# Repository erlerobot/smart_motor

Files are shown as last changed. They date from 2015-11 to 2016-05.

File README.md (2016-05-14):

# smart_servo

### ATmega 328 Microcontroller development

**AVR_OpenServo_V3** -> Stable firmware. Used to create the first prototype.

**AVR_OpenServo_V3-dev** -> Firmware under development more features than the above code.

**OpenServo_Bootloader** -> The bootloader for OpenServo proyect. It is not set in the correct memory place.

### RPI development

**RPI_SmartServo** -> Code for Raspberry Pi.

**RPI_SmartServo_Client** -> Client to send commands to the SmartServo.

**RPI_SmartServo_eagle** -> Schematics and boards for eagle SmartServo.

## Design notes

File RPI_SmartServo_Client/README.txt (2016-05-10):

RPI smart motor client.

To compile gcc -o client client.c

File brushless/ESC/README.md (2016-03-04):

Interesting stuff
===========

- http://vedder.se/2014/01/a-custom-bldc-motor-controller/

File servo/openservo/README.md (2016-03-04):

# OpenServo

El CAD a utilizar en el desarrollo de este proyecto será [Eagle](http://www.cadsoftusa.com/download-eagle/).

- Features: http://www.openservo.com/DocAboutOpenServo
- Site: http://www.openservo.com/
- Wiki: http://www.openservo.com/FrontPage
- European parts list: http://headfuzz.co.uk/openservopartslist
- OpenServo step by step: http://openservo.com/StepByStep

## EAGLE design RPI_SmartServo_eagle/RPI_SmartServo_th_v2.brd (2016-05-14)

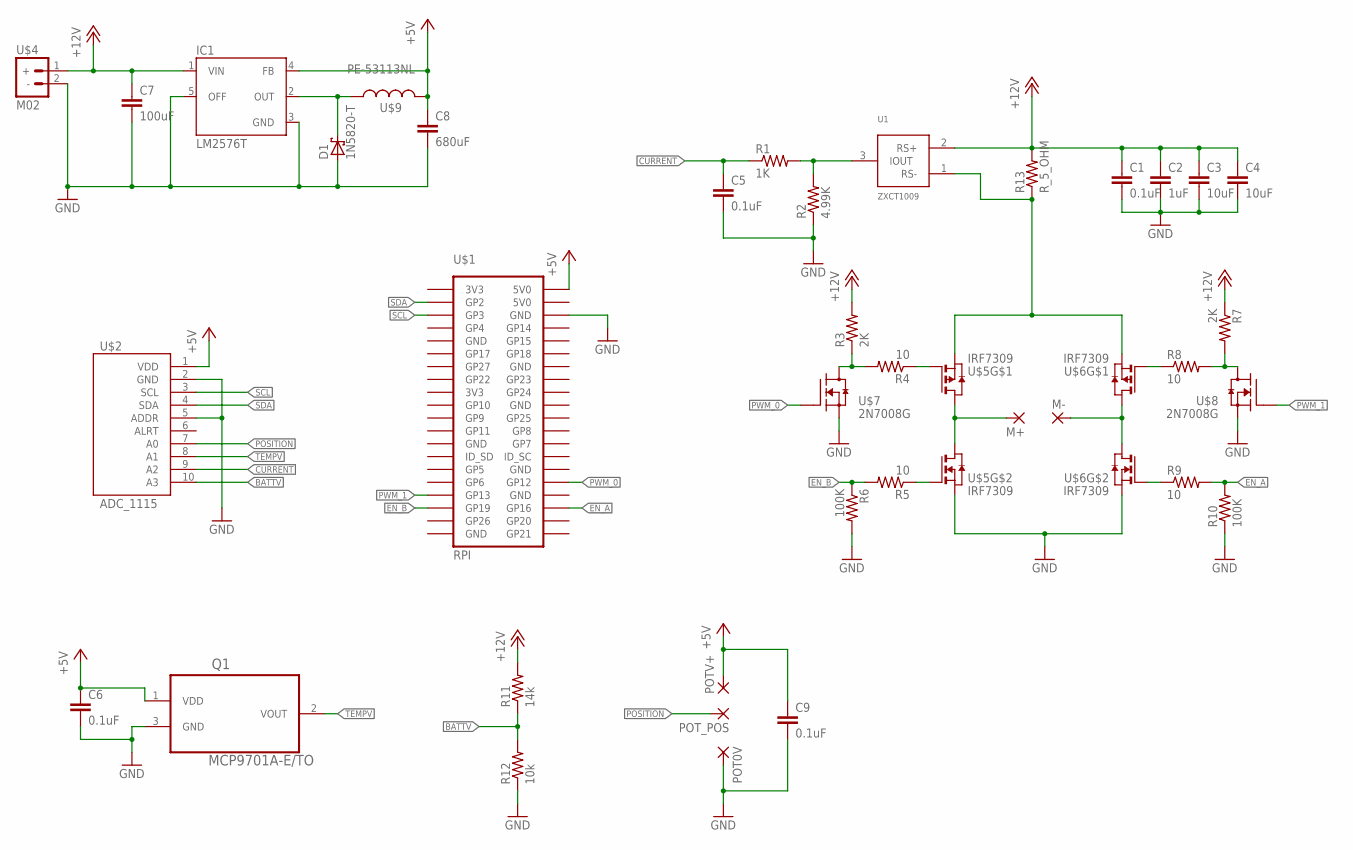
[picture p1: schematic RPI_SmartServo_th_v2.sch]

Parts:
C1, C5, C6, C9: 0.1uF; C025-025X050
C2: 1uF; C025-025X050
C3, C4: 10uF; C025-025X050
C7: 100uF; C025-025X050
C8: 680uF; C025-025X050
D1: 1N5820-T; C4111-15
IC1: LM2576T; TO220-5
M+: 1,6/0,9
M-: 1,6/0,9
POT0V: 1,6/0,9
POTV+: 1,6/0,9
POT_POS: 1,6/0,9
Q1: MCP9701A-E/TO; TO127P254X533-3
R1: 1K; AXIAL-0.4
R2: 4.99K; AXIAL-0.4
R3, R7: 2K; AXIAL-0.4
R4, R5, R8, R9: 10; AXIAL-0.4
R6, R10: 100K; AXIAL-0.4
R11: 14k; AXIAL-0.4
R12: 10k; AXIAL-0.4
R13: R_5_OHM; 0922/22
U1: ZXCT1009; SOT23
U$1: RPI; 2X20
U$2: ADC_1115; 1X10
U$4: M02; 1X02
U$5, U$6: IRF7309; SO8
U$7, U$8: 2N7008G; TO-92
U$9: PE-53113NL; KM-4

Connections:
+5V: C6.1, C8.1, C9.1, IC1.4 (FB), POTV+.1, Q1.1 (VDD), U$1.2 (5V0), U$2.1 (VDD), U$9.P$2 (2)
+12V: C1.1, C2.1, C3.1, C4.1, C7.1, IC1.1 (VIN), R3.P$2 (2), R7.P$1 (1), R11.P$2 (2), R13.2, U1.2 (RS+), U$4.1 (+)
BATTV: R11.P$1 (1), R12.P$2 (2), U$2.10 (A3)
CURRENT: C5.1, R1.P$1 (1), U$2.9 (A2)
EN_A: R9.P$2 (2), R10.P$2 (2), U$1.36 (GP16)
EN_B: R5.P$2 (2), R6.P$1 (1), U$1.35 (GP19)
GND: C1.2, C2.2, C3.2, C4.2, C5.2, C6.2, C7.2, C8.2, C9.2, D1.A, IC1.3 (GND), IC1.5 (OFF), POT0V.1, Q1.3 (GND), R2.P$1 (1), R6.P$2 (2), R10.P$1 (1), R12.P$1 (1), U$1.6 (GND), U$2.2 (GND), U$2.5 (ADDR), U$4.2 (-), U$5.1 (S), U$6.1 (S), U$7.1 (S), U$8.1 (S)
unnamed: R1.P$2 (2), R2.P$2 (2), U1.3 (IOUT)
unnamed: M+.1, U$5.5 (D), U$5.6 (D), U$5.7 (D), U$5.8 (D)
unnamed: R5.P$1 (1), U$5.2 (G)
unnamed: R4.P$1 (1), U$5.4 (G)
unnamed: M-.1, U$6.5 (D), U$6.6 (D), U$6.7 (D), U$6.8 (D)
unnamed: R9.P$1 (1), U$6.2 (G)
unnamed: R8.P$1 (1), U$6.4 (G)
unnamed: D1.C, IC1.2 (OUT), U$9.P$1 (1)
unnamed: R13.1, U1.1 (RS-), U$5.3 (S), U$6.3 (S)
unnamed: R3.P$1 (1), R4.P$2 (2), U$7.3 (D)
unnamed: R7.P$2 (2), R8.P$2 (2), U$8.3 (D)
POSITION: POT_POS.1, U$2.7 (A0)
PWM_0: U$1.32 (GP12), U$7.2 (G)
PWM_1: U$1.33 (GP13), U$8.2 (G)
SCL: U$1.5 (GP3), U$2.3 (SCL)
SDA: U$1.3 (GP2), U$2.4 (SDA)
TEMPV: Q1.2 (VOUT), U$2.8 (A1)

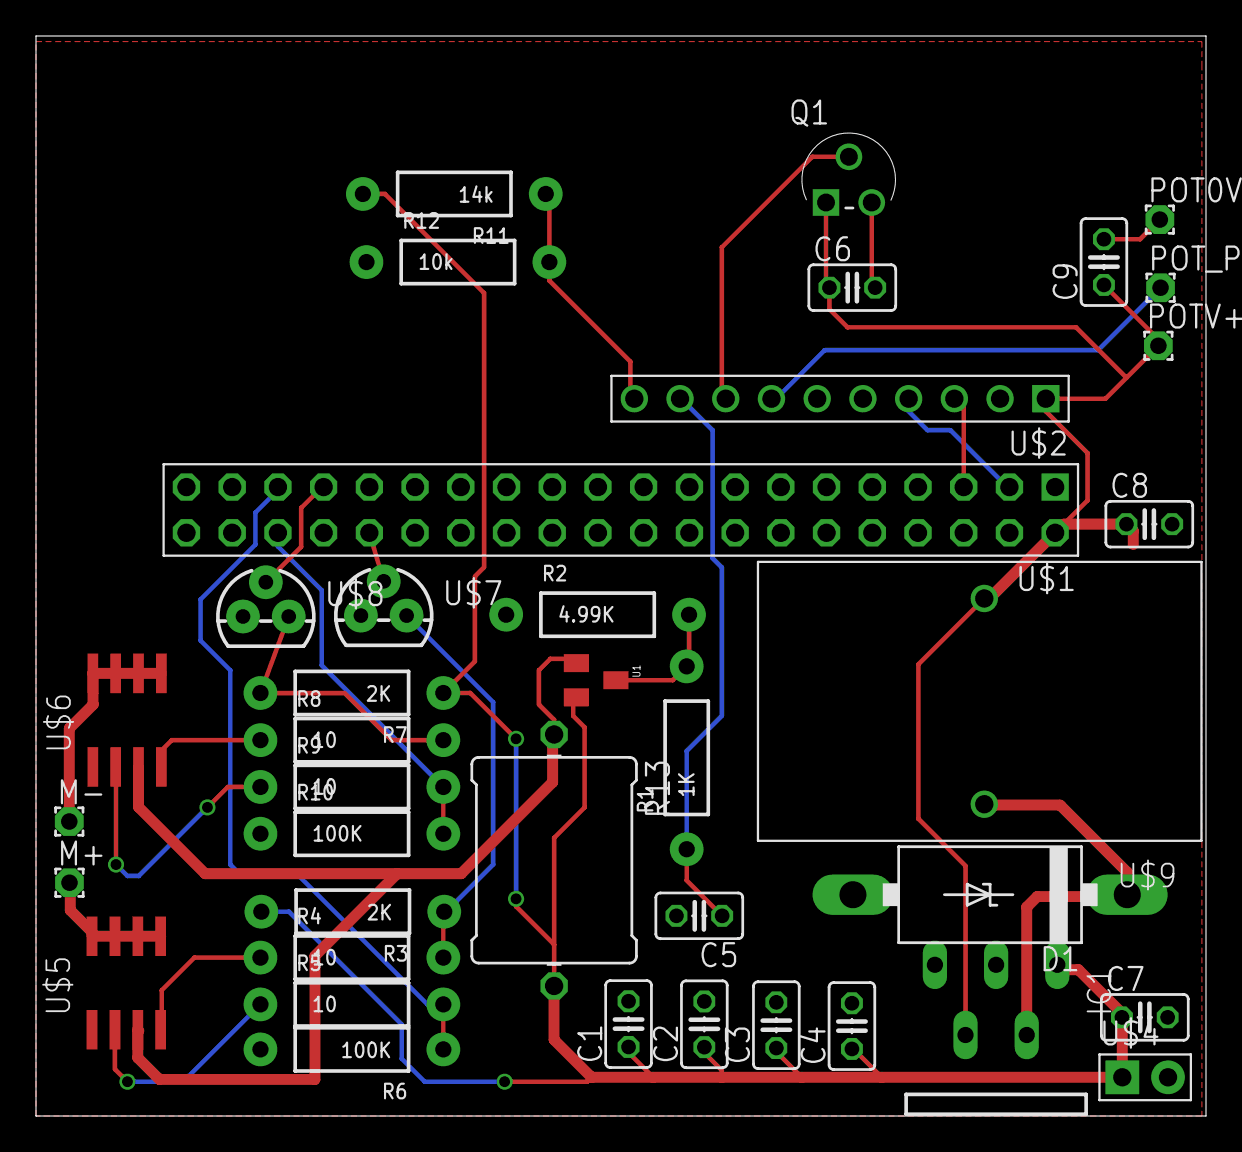
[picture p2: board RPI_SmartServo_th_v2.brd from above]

Board: 2 copper layers, 65.0 x 60.0 mm, 39 parts (0 on the bottom side), 24 nets.

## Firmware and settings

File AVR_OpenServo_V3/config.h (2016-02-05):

/*
    Copyright (c) 2006 Michael P. Thompson <mpthompson@gmail.com>

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
    $Id$
*/

#ifndef _OS_CONFIG_H_
#define _OS_CONFIG_H_ 1

// Enable (1) or disable (0) checksum verification within the
// twi.c module.  When enabled the TWI_CMD_CHECKED_TXN command
// is enabled and basic checksum validation of reads and writes
// of registers can be made for more robust communication with
// the OpenServo.  The checksum code consumes about 280 bytes
// of Flash code space when enabled.
#define TWI_CHECKED_ENABLED         0

// Enable (1) or disable (0) cubic Hermite curve following motion
// functions.  These functions allow the OpenServo to be controlled
// by keypoints along a cubic Hermite curve with each keypoint
// indicating servo position and velocity at a particular time.
#define CURVE_MOTION_ENABLED        0

// Enable (1) or disable (0) some test motion code within the
// main.c module.  This test code can be enabled to test basic
// positioning of the OpenServo without a TWI master controlling
// the OpenServo.  It should normally be disabled.
#define MAIN_MOTION_TEST_ENABLED    0

// Enable (1) or disable (0) standard servo pulse control signaling
// of the seek position.  As of 2/2/07 this feature is still under
// active development.  Please visit the OpenServo forums for the
// current status of this feature.
#define PULSE_CONTROL_ENABLED       1

// Enable (1) or disable (0) the swapping of PWM output A and B.
// This swapping must sometimes enabled depending on whether the
// positive lead to the motor is attached to MOSFET/PWM output A
// or MOSFET/PWM output B.  This option makes this easy to control
// within software.
#define SWAP_PWM_DIRECTION_ENABLED  0

// Enable (1) or disable (0) support for I2C connected encoder.
#define ENCODER_ENABLED             0

// Enable (1) or disable (0) support for full rotation
#define FULL_ROTATION_ENABLED       0

// The known OpenServo hardware types are listed below.
#define HARDWARE_TYPE_UNKNOWN           0
#define HARDWARE_TYPE_FUTABA_S3003      1
#define HARDWARE_TYPE_HITEC_HS_311      2
#define HARDWARE_TYPE_HITEC_HS_475HB    3

// By default the hardware type is unknown.  This value should be
// changed to reflect the hardware type that the code is actually
// being compiled for.
#define HARDWARE_TYPE                   HARDWARE_TYPE_UNKNOWN

// Set configuration values based on HARDWARE_TYPE.
#if (HARDWARE_TYPE == HARDWARE_TYPE_UNKNOWN)

// By default the PID gains are set to zero because they are the
// safest default when implementing an OpenServo on a new hardware.
// These defaults should be overriden by specifying the HARDWARE_TYPE
// above for actual known servo hardware.
#define DEFAULT_PID_PGAIN               0x0000
#define DEFAULT_PID_DGAIN               0x0000
#define DEFAULT_PID_IGAIN               0x0000
#define DEFAULT_PID_DEADBAND            0x00

// Specify default mininimum and maximum seek positions.  The OpenServo will
// not attempt to seek beyond these positions.
#define DEFAULT_MIN_SEEK                0x0060
#define DEFAULT_MAX_SEEK                0x03A0

// Default pwm frequency divider.
#define DEFAULT_PWM_FREQ_DIVIDER        0x0040

#elif (HARDWARE_TYPE == HARDWARE_TYPE_FUTABA_S3003)

// Futaba S3003 hardware default PID gains.
#define DEFAULT_PID_PGAIN               0x0600
#define DEFAULT_PID_DGAIN               0x0C00
#define DEFAULT_PID_IGAIN               0x0000
#define DEFAULT_PID_DEADBAND            0x01

// Futaba S3003 hardware default mininimum and maximum seek positions.
#define DEFAULT_MIN_SEEK                0x0060
#define DEFAULT_MAX_SEEK                0x03A0

// Futaba S3003 hardware default pwm frequency divider.
#define DEFAULT_PWM_FREQ_DIVIDER        0x0040

#elif (HARDWARE_TYPE == HARDWARE_TYPE_HITEC_HS_311)

// Hitec HS-311 hardware default PID gains.
#define DEFAULT_PID_PGAIN               0x0600
#define DEFAULT_PID_DGAIN               0x0C00
#define DEFAULT_PID_IGAIN               0x0000
#define DEFAULT_PID_DEADBAND            0x01

// Hitec HS-311 hardware default mininimum and maximum seek positions.
#define DEFAULT_MIN_SEEK                0x0060
#define DEFAULT_MAX_SEEK                0x03A0

// Hitec HS-311 hardware default pwm frequency divider.
#define DEFAULT_PWM_FREQ_DIVIDER        0x0040

#elif (HARDWARE_TYPE == HARDWARE_TYPE_HITEC_HS_475HB)

// Hitec HS-475HB hardware default PID gains.
#define DEFAULT_PID_PGAIN               0x0600
#define DEFAULT_PID_DGAIN               0x0C00
#define DEFAULT_PID_IGAIN               0x0000
#define DEFAULT_PID_DEADBAND            0x01

// Hitec HS-475HB hardware default mininimum and maximum seek positions.
#define DEFAULT_MIN_SEEK                0x0060
#define DEFAULT_MAX_SEEK                0x03A0

// Hitec HS-475HB hardware default pwm frequency divider.
#define DEFAULT_PWM_FREQ_DIVIDER        0x0040

#endif

#endif // _OS_ADC_H_

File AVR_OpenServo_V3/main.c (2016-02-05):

/*
    Copyright (c) 2006 Michael P. Thompson <mpthompson@gmail.com>

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
    $Id$
*/

#include <inttypes.h>
#include <avr/interrupt.h>
#include <avr/io.h>

#include "openservo.h"
#include "config.h"
#include "adc.h"
#include "eeprom.h"
#include "motion.h"
#include "pid.h"
#include "power.h"
#include "pwm.h"
#include "seek.h"
#include "pulsectl.h"
#include "timer.h"
#include "twi.h"
#include "watchdog.h"
#include "registers.h"
#include "swi2c.h"
#include "enc.h"

static void config_pin_defaults(void)
// Configure pins to their default states to conform to recommendation that all
// AVR MCU pins have a defined level.  We do this by configuring unused pins
// as inputs and enabling the internal pull-ups.
{
    // Configure unused port B pins as inputs and enable internal pull-up resistor.
    DDRB = (0<<DDB7) | (0<<DDB6) | (0<<DDB5) | (0<<DDB4) |
           (0<<DDB3) | (1<<DDB2) | (1<<DDB1) | (0<<DDB0);
    PORTB = (1<<PORTB7) | (1<<PORTB6) | (1<<PORTB5) | (1<<PORTB4) |
            (1<<PORTB3) | (0<<PORTB2) | (0<<PORTB1) | (1<<PORTB0);

    // Configure unused port C pins as inputs and enable internal pull-up resistor.
    DDRC = (0<<DDC6) | (0<<DDC5) | (0<<DDC4) |
           (0<<DDC3) | (0<<DDC2) | (0<<DDC1) | (0<<DDC0);
    PORTC = (1<<PORTC6) | (1<<PORTC5) | (1<<PORTC4) |
            (1<<PORTC3) | (1<<PORTC2) | (1<<PORTC1) | (1<<PORTC0);

    // Configure port D pins as inputs and enable internal pull-up resistor.
    DDRD = (1<<DDD7) | (0<<DDD6) | (1<<DDD5) | (1<<DDD4) |
           (1<<DDD3) | (1<<DDD2) | (0<<DDD1) | (0<<DDD0);
    PORTD = (1<<PORTD7) | (1<<PORTD6) | (0<<PORTD5) | (1<<PORTD4) |
            (0<<PORTD3) | (0<<PORTD2) | (1<<PORTD1) | (1<<PORTD0);
}


static void handle_twi_command(void)
{
    uint8_t command;

    // Get the command from the receive buffer.
    command = twi_receive_byte();

    switch (command)
    {
        case TWI_CMD_RESET:

            // Reset the servo.
            watchdog_hard_reset();

            break;

        case TWI_CMD_PWM_ENABLE:

            // Enable PWM to the servo motor.
            pwm_enable();

            break;

        case TWI_CMD_PWM_DISABLE:

            // Disable PWM to the servo motor.
            pwm_disable();

            break;

        case TWI_CMD_WRITE_ENABLE:
			
            // Enable write to read/write protected registers.
            registers_write_enable();

            break;

        case TWI_CMD_WRITE_DISABLE:

            // Disable write to read/write protected registers.
            registers_write_disable();

            break;

        case TWI_CMD_REGISTERS_SAVE:

            // Save register values into EEPROM.
            eeprom_save_registers();

            break;

        case TWI_CMD_REGISTERS_RESTORE:

            // Restore register values into EEPROM.
            eeprom_restore_registers();

            break;

        case TWI_CMD_REGISTERS_DEFAULT:

            // Restore register values to factory defaults.
            registers_defaults();
            break;

        case TWI_CMD_EEPROM_ERASE:

            // Erase the EEPROM.
            eeprom_erase();

            break;

        case TWI_CMD_VOLTAGE_READ:

            // Request a voltage reading.
            adc_read_voltage();

            break;

#if CURVE_MOTION_ENABLED
        case TWI_CMD_CURVE_MOTION_ENABLE:

            // Enable curve motion handling.
            motion_enable();

            break;

        case TWI_CMD_CURVE_MOTION_DISABLE:

            // Disable curve motion handling.
            motion_disable();

            break;

        case TWI_CMD_CURVE_MOTION_RESET:

            // Reset the motion to the current position.
#if ENCODER_ENABLED
            motion_reset(enc_get_position_value());
#else
            motion_reset(adc_get_position_value());
#endif

            break;

        case TWI_CMD_CURVE_MOTION_APPEND:

            // Append motion curve data stored in the registers.
            motion_append();

            break;
#endif

        default:

            // Ignore unknown command.
            break;
    }
}


int main (void)
{	
    // Configure pins to the default states.
    config_pin_defaults();
	
    // Initialize the watchdog module.
    watchdog_init();

    // First, initialize registers that control servo operation.
    registers_init();

    // Initialize the PWM module.
    pwm_init();

    // Initialize the ADC module.
    adc_init();

    // Initialize the PID algorithm module.
    pid_init();
	
#if CURVE_MOTION_ENABLED
    // Initialize curve motion module.
    motion_init();
#endif

    // Initialize the power module.
    power_init();

#if PULSE_CONTROL_ENABLED
    pulse_control_init();
#endif

#if ENCODER_ENABLED
    // Initialize software I2C to talk with encoder.
    swi2c_init();
#endif
	
    // Initialize the TWI slave module.
    twi_slave_init(registers_read_byte(REG_TWI_ADDRESS));
	
    // Finally initialize the timer.
    timer_set(0);

    // Enable interrupts.
    sei();
	
#if !ENCODER_ENABLED
    // Wait until initial position value is ready.
//    while (!adc_position_value_is_ready());				////atasco papel
#endif
	
#if CURVE_MOTION_ENABLED
    // Reset the curve motion with the current position of the servo.
#if ENCODER_ENABLED
    motion_reset(enc_get_position_value());
#else
    motion_reset(adc_get_position_value());
#endif
#endif

    // Set the initial seek position and velocity.
#if ENCODER_ENABLED
    registers_write_word(REG_SEEK_POSITION_HI, REG_SEEK_POSITION_LO, enc_get_position_value());
#else
    registers_write_word(REG_SEEK_POSITION_HI, REG_SEEK_POSITION_LO, adc_get_position_value());
#endif
    registers_write_word(REG_SEEK_VELOCITY_HI, REG_SEEK_VELOCITY_LO, 0);

    // XXX Enable PWM and writing.  I do this for now to make development and
    // XXX tuning a bit easier.  Constantly manually setting these values to
    // XXX turn the servo on and write the gain values get's to be a pain.
    pwm_enable();
    registers_write_enable();
	
    // This is the main processing loop for the servo.  It basically looks
    // for new position, power or TWI commands to be processed.
    for (;;)
    {	
        // Is position value ready?
#if !ENCODER_ENABLED
        if (adc_position_value_is_ready())
		
#endif
        {   //PORTD = (1<<PORTD5);
            int16_t pwm;
            int16_t position;

#if PULSE_CONTROL_ENABLED
            // Give pulse control a chance to update the seek position.
            pulse_control_update();
#endif

#if CURVE_MOTION_ENABLED
            // Give the motion curve a chance to update the seek position and velocity.
            motion_next(10);
#endif

            // Get the new position value.
#if ENCODER_ENABLED
            position = (int16_t) enc_get_position_value();
#else
            position = (int16_t) adc_get_position_value();
#endif

#if ENCODER_ENABLED
            if (position >= 0)
#endif
            {
                // Call the PID algorithm module to get a new PWM value.
                pwm = pid_position_to_pwm(position);

                // Update the servo movement as indicated by the PWM value.
                // Sanity checks are performed against the position value.
                pwm_update(position, pwm);
            }
        }

        // Is a power value ready?
        if (adc_power_value_is_ready())
        {
            // Get the new power value.
            uint16_t power = adc_get_power_value();

            // Update the power value for reporting.
            power_update(power);
        }

        // Was a command recieved?
        if (twi_data_in_receive_buffer())
        {
            // Handle any TWI command.
            handle_twi_command();
        }

#if MAIN_MOTION_TEST_ENABLED
        // This code is in place for having the servo drive itself between
        // two positions to aid in the servo tuning process.  This code
        // should normally be disabled in config.h.
#if CURVE_MOTION_ENABLED
        if (motion_time_left() == 0)
        {
            registers_write_word(REG_CURVE_DELTA_HI, REG_CURVE_DELTA_LO, 2000);
            registers_write_word(REG_CURVE_POSITION_HI, REG_CURVE_POSITION_LO, 0x0100);
            motion_append();
            registers_write_word(REG_CURVE_DELTA_HI, REG_CURVE_DELTA_LO, 1000);
            registers_write_word(REG_CURVE_POSITION_HI, REG_CURVE_POSITION_LO, 0x0300);
            motion_append();
            registers_write_word(REG_CURVE_DELTA_HI, REG_CURVE_DELTA_LO, 2000);
            registers_write_word(REG_CURVE_POSITION_HI, REG_CURVE_POSITION_LO, 0x0300);
            motion_append();
            registers_write_word(REG_CURVE_DELTA_HI, REG_CURVE_DELTA_LO, 1000);
            registers_write_word(REG_CURVE_POSITION_HI, REG_CURVE_POSITION_LO, 0x0100);
            motion_append();
        }
#else
        {
            // Get the timer.
            uint16_t timer = timer_get();

            // Reset the timer if greater than 800.
            if (timer > 800) timer_set(0);

            // Look for specific events.
            if (timer == 0)
            {
                registers_write_word(REG_SEEK_HI, REG_SEEK_LO, 0x0100);
            }
            else if (timer == 400)
            {
                registers_write_word(REG_SEEK_HI, REG_SEEK_LO, 0x0300);
            }
        }
#endif
#endif
    }
	
	
	
    return 0;
}

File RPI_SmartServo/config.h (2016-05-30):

/**
 *  project  :  RPI_SmartServo          
 *  
 *  @file config.h
 *  @brief Configuration file for RPI_SmartServo
 * 
 *  @note 
 *
 *      none
 *
 *  \code
 *  MODIFICATION HISTORY:
 *
 *  Ver   Who        Date        Changes
 *  ----- ---------- ----------  -------------------------------------
 *  1.00 jlamperez  6/3/2016  First release
 * 
 *  \endcode
 *
 *  Copyright (c) 2016, Jorge Lampérez. All rights reserved.
 */

#ifndef CONFIG_H_
#define CONFIG_H_ 1

#define RPI_0 0
#define RPI_1 1
#define RPI_2 2

#define BITS_12 12
#define BITS_10 10

/** Define different options for RPI Servo.
 @todo todo
 Configuration for the ADS1115
 */
#define RPI_BOARD RPI_2
#define ADC_RESOLUTION BITS_12

/**
 *  TIMER configuration.
 */
//#define CONFIG_TIMER 100000000 //100ms
//#define CONFIG_TIMER  10000000 //10ms
#define CONFIG_TIMER  50000000 //50ms Good
//#define CONFIG_TIMER  30000000 //30ms Falla
//#define CONFIG_TIMER  40000000 //40ms Falla
//#define CONFIG_TIMER  45000000 //45ms Falla
/**
 *  Debugger configuration.
 */

//#define CONFIG_DEBUGGER 0

/**
 *  Board.  RPI_0, RPI_1, RPI_2
 *  PWM and EN GPIO can be changed
 */

/*
 * RPIO_0
 */
#if (RPI_BOARD == 0)
// PWM GPIO
#define CONFIG_PWM0_GPIO X // pin X
#define CONFIG_PWM1_GPIO X // pin X
// EN_A and EN_N GPIO
#define CONFIG_EN_A_GPIO X //pin X
#define CONFIG_EN_B_GPIO X //pin X
/*
 * RPIO_1
 */
#elif (RPI_BOARD == 1)
// PWM GPIO
#define CONFIG_PWM0_GPIO 12 // pin X
#define CONFIG_PWM1_GPIO 13 // pin X
// EN_A and EN_N GPIO
#define CONFIG_EN_A_GPIO 16 //pin X
#define CONFIG_EN_B_GPIO 19 //pin X
/*
 * RPIO_2
 */
#elif (RPI_BOARD == 2)
// PWM GPIO
#define CONFIG_PWM0_GPIO 12 // pin 32
#define CONFIG_PWM1_GPIO 13 // pin 33
// EN_A and EN_N GPIO
#define CONFIG_EN_A_GPIO 16 //pin36
#define CONFIG_EN_B_GPIO 19 //pin35
#endif


/**
 *  ADC resolution configuration for pid and pwm
 */

/*
 * ADC 10 bits
 */
#if (ADC_RESOLUTION == BITS_10)
/**
 *  ADC and Potentiometer resolution values to convert to voltage and grades
 */
#define ADC_RES_CONSTANT 0.006  //(6.1444/2^10)
#define POT_RES_CONSTANT 3.78   //(5V/ADC_RES)/220º
/**
 *  PID configuration.
 */

// The minimum and maximum servo position as defined by 10-bit ADC values.
#define CONFIG_PID_MIN_POSITION (0)
//The ADC effective bits are 15 but because of noise we take 10.
#define CONFIG_PID_MAX_POSITION (1024)
// The minimum and maximum output.
#define CONFIG_PID_MAX_OUTPUT          (255)
#define CONFIG_PID_MIN_OUTPUT          (-CONFIG_PID_MAX_OUTPUT)
// Default PID values
#define CONFIG_DEFAULT_PID_DEADBAND    0x01
#define CONFIG_DEFAULT_PID_PGAIN       0x0060
#define CONFIG_DEFAULT_PID_DGAIN       0x0000
#define CONFIG_DEFAULT_PID_IGAIN       0x0000
// Max and min seek values
#define CONFIG_DEFAULT_MIN_SEEK        0x0001
#define CONFIG_DEFAULT_MAX_SEEK        0x0CFD

/**
 *  PWM and EN configuration.
 */

// PWM frequency = 19.2 Mhz/PWM_RANGE/CLOCK_DIV.
// PWM frequency of 9765.525 Hz with next two config values.
#define CONFIG_PWM_RANGE 1024
#define CONFIG_PWM_CLOCK_DIV 2
// Delay between direction change of the chopper
// This value should be maximum the period of the PWM
#define	CONFIG_PWM_DIR_CHANGE_DELAY	100 //for 1024
// PWM maximum position value
#define CONFIG_PWM_MAX_POSITION  (1023)

/*
 * ADC 12 bits
 */
#elif (ADC_RESOLUTION == BITS_12)
/**
 *  ADC and Potentiometer resolution values to convert to voltage and grades
 */
#define ADC_RES_CONSTANT 0.0015  //(6.144/2^12)
#define POT_RES_CONSTANT 15.15   //(5V/ADC_RES)/220º
/**
 *  PID configuration.
 */
// The minimum and maximum servo position as defined by 12-bit ADC values.
#define CONFIG_PID_MIN_POSITION (0)
//The ADC effective bits are 15 but because of noise we take 12.
#define CONFIG_PID_MAX_POSITION (4096)
// The minimum and maximum output.
#define CONFIG_PID_MAX_OUTPUT          (255)
#define CONFIG_PID_MIN_OUTPUT          (-CONFIG_PID_MAX_OUTPUT)
// Default PID values
#define CONFIG_DEFAULT_PID_DEADBAND    0x01
#define CONFIG_DEFAULT_PID_PGAIN       0x0015
#define CONFIG_DEFAULT_PID_DGAIN       0x0000
//#define CONFIG_DEFAULT_PID_PGAIN       0x0028
//#define CONFIG_DEFAULT_PID_DGAIN       0x0023
#define CONFIG_DEFAULT_PID_IGAIN       0x0000
// Max and min seek values
#define CONFIG_DEFAULT_MIN_SEEK        0x0001
#define CONFIG_DEFAULT_MAX_SEEK        0x0CFD //0x0D08
/**
 *  PWM and EN configuration.
 */
// PWM frequency = 19.2 Mhz/PWM_RANGE/CLOCK_DIV.
// PWM frequency of 2343.75Hz Hz with next two config values.
#define CONFIG_PWM_RANGE 4096
#define CONFIG_PWM_CLOCK_DIV 2
// Delay between direction change of the chopper
// This value should be maximum the period of the PWM
#define	CONFIG_PWM_DIR_CHANGE_DELAY	500  //for 4096
// PWM maximum position value
#define CONFIG_PWM_MAX_POSITION  (4095)
#endif


#endif //CONFIG_H_

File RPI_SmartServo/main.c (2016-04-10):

/**
 *  project  : 	RPI_SmartServo			
 * 	
 * 	@file main.c
 *  @brief main file
 * 
 *  @note 
 *
 *  	none
 *
 *  \code
 *  MODIFICATION HISTORY:
 *
 *  Ver   Who        Date        Changes
 *  ----- ---------- ----------  -------------------------------------
 *  1.00 jlamperez  6/3/2016  First release
 * 
 *  \endcode
 *
 *	Copyright (c) 2016, Jorge Lampérez. All rights reserved.
 */

/* 
	#include modules
*/
#include <wiringPi.h>	
#include <stdint.h>
#include <stdio.h>
#include <pthread.h>
#include <time.h>
#include "Framework/modules/pwm.h"
#include "Framework/modules/registers.h"
#include "Framework/modules/pid.h"
#include "Framework/modules/adc.h"
#include "Framework/modules/timer.h"
#include "Framework/modules/server.h"
#include "config.h"

void createServer();//Creates the server thread to recive commands via TCP/IP
void* serverThread(void*);

int main(void)
{
	printf("Smart Servo\n");
// MODULE INITIALIZATION

	// This initialises the wiringPi system and 
	// assumes that the calling program is going 
	// to be using the Broadcom GPIO pin numbers directly.
	wiringPiSetupGpio();
	// Configure pins to the default states

	// First, initialize registers that control servo operation
	// Set the initial seek position and velocity
	REGISTERS_init();
	// Initialize the PWM module
	PWM_init();
	// Initialize ADC module
	ADC_init();
	// Initialize the PID algorithm module
	PID_init();
	// Initialize timer 10 ms.
	TIMER_init(CONFIG_TIMER);
//MODULE INITIALIZATION END
	
	//Create Server thread for communication
	createServer();

	// Main processing loop for the servo. It basically 
	// looks for new position, power or TWI commands to 
	// be processed.
	for(;;)
	{	
		
		static int i=0;
		if(adc_position_value_is_ready())
		{   printf("Time: %f seconds\n", (double)clock() /CLOCKS_PER_SEC);
		    
		    // Is position value ready?
            clock_t tic = clock();
			int16_t pwm;
			int16_t position;
			
			/** @todo */
			// get position() better ??
			position = adc_get_position_value();

			// Call the PID algorithm module to get a new PWM value. 
			pwm = PID_position_to_pwm(position);

			// Update the servo movement as indicated by the PWM value.
			PWM_update(position, pwm);
                        printf("MAIN position value is: %d \n", position);
			printf("MAIN pwm value is: %d \n", pwm);
			printf("------------%i--------------\n",i);
			i++;
			clock_t toc = clock();
		    printf("Elapsed: %f seconds\n", (double)(toc-tic) /CLOCKS_PER_SEC);
		}
		// Is a power value ready?

			// Get the new power value.

			// Update the power value for reporting.

		// Was a command received?

			// handle twi command
	}
}

void createServer(){
	pthread_t thread_id;
	if (pthread_create(&thread_id, NULL, serverThread, 0) < 0) {
		perror("could not create the server thread");
	}
}

void *serverThread(void *server_desc){
	SERVER_init();
	return 0;
}

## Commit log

2015-11-27 Add some structure and initial pointers for ESCs
    [openservo-v27.brd, openservo-v27.sch]
2015-11-27 Add Open-BLDC
2015-12-03 Add CAD
2016-01-21 Error al compilar pwm comentadas dos lineas Añadir proyecto bootloader
    [config.h, main.c, pwm.c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]
2016-01-25 OpenServo v2.8 schematic
    The schematic of the first OpenServo prototype
    [openservo-v28.sch]
2016-01-28 Descomentar lineas pwm.c
2016-02-15 Some modules ported to raspberry pi. Not compiled. Could be errors.
    [adc.c, config.h, main.c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]
2016-02-17 Changes in pid and pwm files. Now H bridge signals work well.
2016-03-04 modificado: RPI_SmartServo/Framework/modules/adc.c modificado: RPI_SmartServo/Framework/modules/adc.h modificado: RPI_SmartServo/Framework/modules/pid.c modificado: RPI_SmartServo/Framework/modules/p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
    [openservo-v28.sch]
2016-03-04 new file: RPI_SmartServo/Framework/modules/ads1115.c new file: RPI_SmartServo/Framework/modules/ads1115.h new file: RPI_SmartServo/Framework/modules/i2c.c new file: RPI_SmartServo/Framework/modules/i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
2016-03-06 Changes to make adc work. Changes to be committed: modified: Framework/modules/adc.c modified: Framework/modules/adc.h modified: Framework/modules/ads1115.c modified: Framework/modules/ads1115.h modi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
2016-03-06 ads1115->change in SPS defines pid -> velocity
2016-03-18 modified: RPI_SmartServo/Framework/modules/ads1115.c modified: RPI_SmartServo/Framework/modules/pwm.c modified: RPI_SmartServo/main.c delay in pwm file not to burn h-bridge. proving adc, not working 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
    [ads1115.c, main.c, pwm.c]
2016-03-21 4 file added: server.c, server.h, service.c and service.h to have TCP/IP server client communication. Changes: - Create thread in main for server. - Change MSG value to uint16_t - Use register.h func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
2016-03-24 Changes to support Client server communication with servo. modified: RPI_SmartServo/Framework/modules/server.c modified: RPI_SmartServo/Makefile modified: RPI_SmartServo/main.c
2016-03-24 In previous commit also fixed ads1115 error when writing to the CONFIG register. modified: RPI_SmartServo/Framework/modules/ads1115.c
    [ads1115.c]
2016-03-24 Some new documentation for server and service modules. modificado: RPI_SmartServo/Framework/modules/registers.c modificado: RPI_SmartServo/Framework/modules/server.c modificado: RPI_SmartServo/Framew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
2016-03-24 Changes in ads1115 to return 12 bits values instead of 15, noise. PID and PWM configuration options moved to config file.
    modificado: RPI_SmartServo/Framework/modules/ads1115.c
    modificado: RPI_SmartServo/Framework/modules/pid.c
    modificado: RPI_SmartServo/Framework/modules/pwm.c
    modificado: RPI_SmartServo/config.h
    [ads1115.c, config.h, pid.c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]
2016-03-24 12 bits values adc modificado: RPI_SmartServo/Framework/modules/ads1115.c
2016-03-25 Change in configuration file settings. modified: RPI_SmartServo/Framework/modules/pwm.c modified: RPI_SmartServo/config.h
2016-03-25 Changes for Debugger configuration modificado: RPI_SmartServo/Framework/modules/adc.c modificado: RPI_SmartServo/Framework/modules/ads1115.c modificado: RPI_SmartServo/Framework/modules/pid.c modific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
2016-03-25 RPI servo basic working. Changed ADS delay. Changed in config the p_gain and d_gain In the main for time measure. modified: Framework/modules/ads1115.c modified: config.h modified: main.c
2016-04-10 Change in registers for current and battery. Change in config.h to support different options. Change in adc to measure current voltage and battery
    Cambios para hacer commit:
    modificado: RPI_SmartServo/Framework/modules/adc.c
    modificado: RPI_SmartServo/Framework/modules/registers.c
    modificado: RPI_SmartServo/Framework/modules/registers.h
    modificado: RPI_SmartServo/main.c
    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
2016-04-11 Added rpiservo interface abstraction for communication. Changes in adc, ads1115 and registers modifying for temperature. Cambios para hacer commit: modificado: RPI_SmartServo/Framework/modules/adc.c 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
2016-04-11 Changes in adc and ads115 to improve prototype with temp, battery and current. Changes to be committed: modified: RPI_SmartServo/Framework/modules/adc.c modified: RPI_SmartServo/Framework/modules/ads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
2016-04-11 Improving the communication interface Changes to be committed: modified: RPI_SmartServo/Framework/modules/adc.c modified: RPI_SmartServo/Framework/modules/ads1115.c modified: RPI_SmartServo/Framework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
2016-04-15 Changes to support new communication interface. Cambios para hacer commit: modificado: RPI_SmartServo/Framework/modules/adc.c modificado: RPI_SmartServo/Framework/modules/ads1115.c modificado: RPI_Sm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
2016-04-28 Eagle files uploaded new file: RPI_SmartServo_eagle/RPI_SmartServo_th.brd new file: RPI_SmartServo_eagle/RPI_SmartServo_th.sch
    [RPI_SmartServo_th.brd, RPI_SmartServo_th.sch]
2016-04-28 Ground plane added modificado: RPI_SmartServo_eagle/RPI_SmartServo_th.brd
    [RPI_SmartServo_th.brd]
2016-04-28 Changed the Current Sensor modificado: RPI_SmartServo_eagle/RPI_SmartServo_th.brd modificado: RPI_SmartServo_eagle/RPI_SmartServo_th.sch
    [RPI_SmartServo_th.brd, RPI_SmartServo_th.sch]
2016-05-04 New board and schematics files. new file: RPI_SmartServo_eagle/RPI_SmartServo_th_v2.brd new file: RPI_SmartServo_eagle/RPI_SmartServo_th_v2.sch
    [RPI_SmartServo_th_v2.brd, RPI_SmartServo_th_v2.sch]
2016-05-10 Changes for new interface: modified: RPI_SmartServo/Framework/modules/ads1115.c modified: RPI_SmartServo/Framework/modules/rpiservo.c modified: RPI_SmartServo/Framework/modules/rpiservo.h modified: R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
2016-05-14 Change in RPI_SmartServo_th_v2.brd modificado: RPI_SmartServo_eagle/RPI_SmartServo_th_v2.brd
    [RPI_SmartServo_th_v2.brd]
2016-05-16 Timer code to probe ADS1115
2016-05-16 Changes to be committed: modified: Makefile modified: Timer.c
2016-05-17 Add make clean in the makefile to erase de .o files.

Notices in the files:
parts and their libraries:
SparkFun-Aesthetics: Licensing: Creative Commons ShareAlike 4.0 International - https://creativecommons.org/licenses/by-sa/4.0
